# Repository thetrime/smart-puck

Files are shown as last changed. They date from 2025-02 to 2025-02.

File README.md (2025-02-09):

# Smart Puck
> But what if we went _smaller_?

# Configuration
You need three config files to run smart-puck. See the README.md file in the `config` directory

# Prerequisites
Obviously you need the hardware. 
FIXME: Details to be filled in once I work out what the hardware is ^^

You also need:
   * python
   * pip

# Installation
A shell script is available for bash users. (`mpremote cp *.py :` doesn't work on Windows). A workaround is to stop using Windows.

You can install it by just running `./install.sh` after plugging in your pico. Note that you also have to flash the Micropython firmware to it first.

That's it. Reboot and it's ready!

# To do list
## Code
   * Nothing? That doesn't sound right
## Hardware
   * Finish the schematic and PCB design
   * Create a STL for the case

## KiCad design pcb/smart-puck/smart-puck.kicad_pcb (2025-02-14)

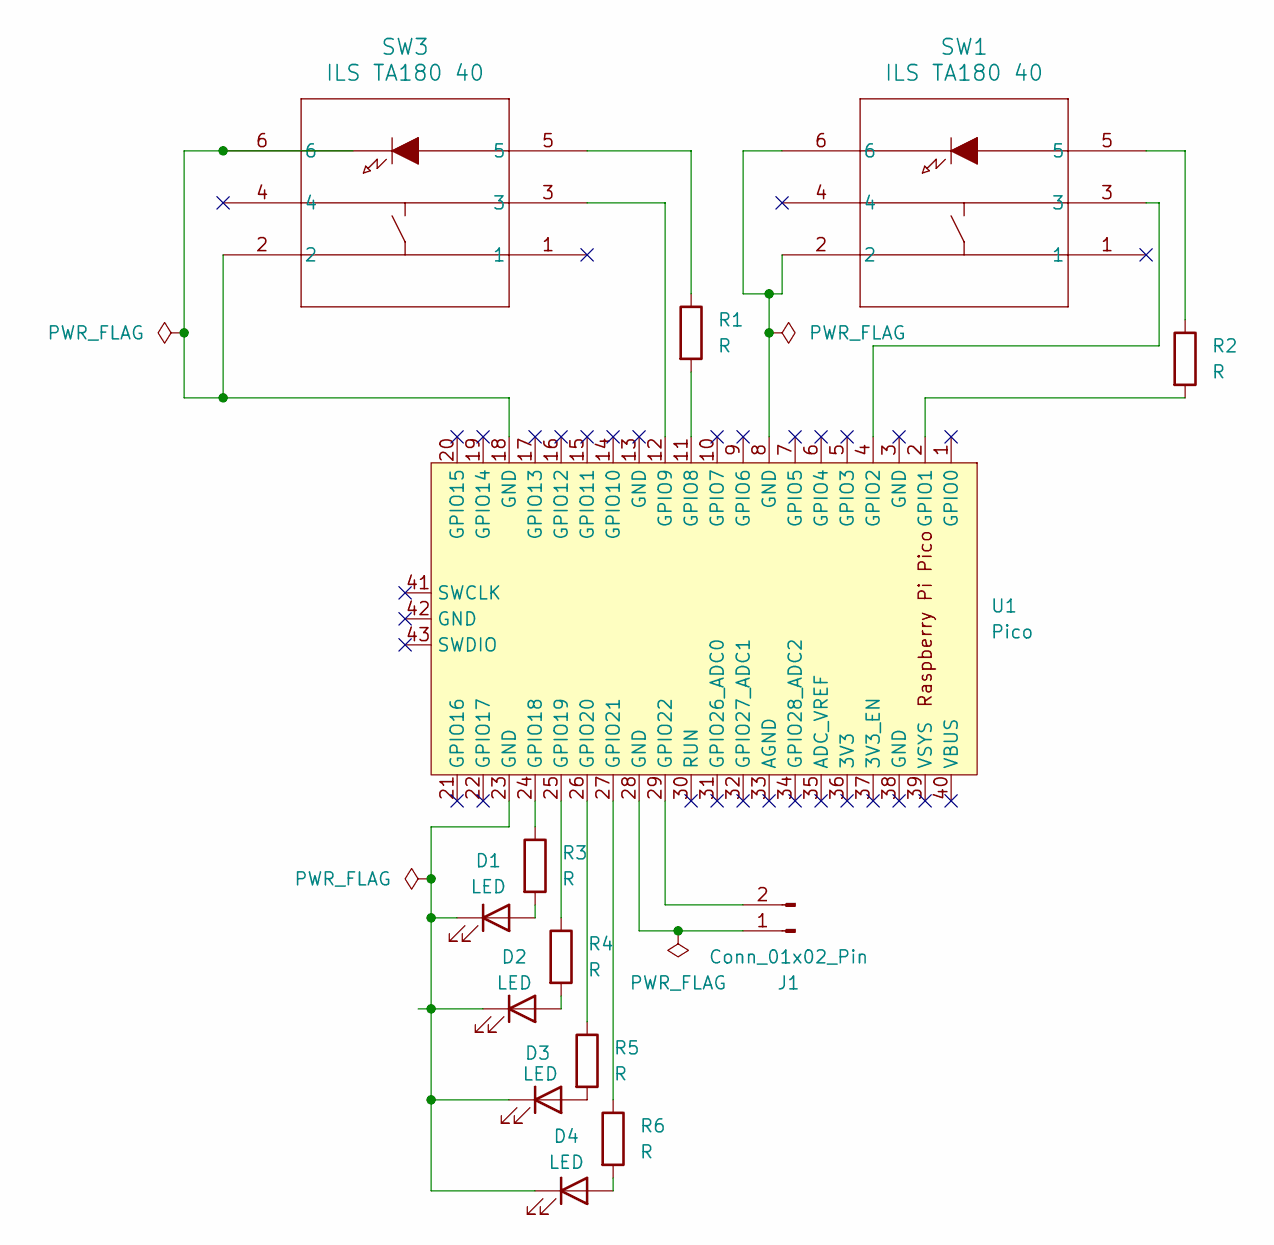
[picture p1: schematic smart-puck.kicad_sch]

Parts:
D1, D2, D3, D4: LED; LED_D5.0mm_Clear
J1: Conn_01x02_Pin; PinHeader_1x02_P2.54mm_Vertical
R1, R2, R3, R4, R5, R6: R; R_Axial_DIN0309_L9.0mm_D3.2mm_P12.70mm_Horizontal
SW1, SW3: ILS TA180 40; SW6_ILS TA180 40_CNK
U1: Pico; RPi_Pico_SMD_TH

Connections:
unnamed: D1.2 (A), R3.2
unnamed: D1.1 (K), D2.1 (K), D3.1 (K), D4.1 (K), U1.23 (GND)
unnamed: D2.2 (A), R4.2
unnamed: D3.2 (A), R5.2
unnamed: D4.2 (A), R6.2
unnamed: J1.1, U1.28 (GND)
unnamed: J1.2, U1.29 (GPIO22)
unnamed: R1.1, SW3.5
unnamed: R2.1, SW1.5
unnamed: SW1.2, SW1.6, U1.8 (GND)
unnamed: SW3.2, SW3.6, U1.18 (GND)
unnamed: R2.2, U1.2 (GPIO1)
unnamed: SW1.3, U1.4 (GPIO2)
unnamed: R1.2, U1.11 (GPIO8)
unnamed: SW3.3, U1.12 (GPIO9)
unnamed: R3.1, U1.24 (GPIO18)
unnamed: R4.1, U1.25 (GPIO19)
unnamed: R5.1, U1.26 (GPIO20)
unnamed: R6.1, U1.27 (GPIO21)

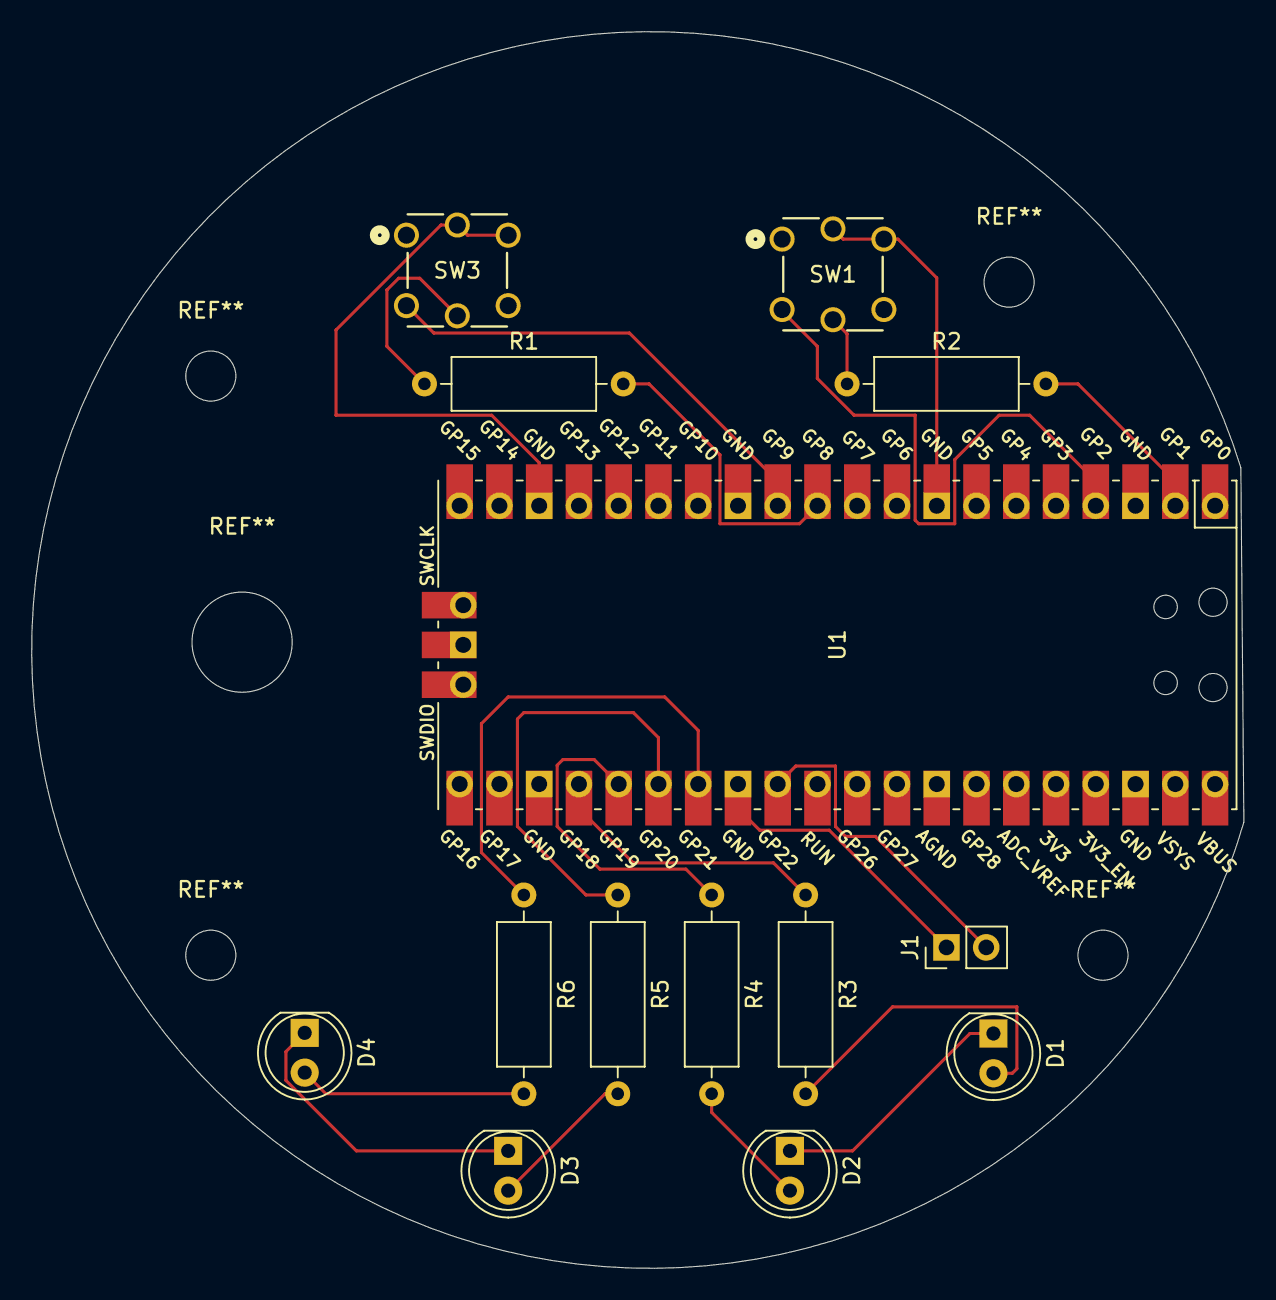
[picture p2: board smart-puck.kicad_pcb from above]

Board: 2 copper layers, 77.4 x 79.0 mm, 14 parts (0 on the bottom side), 19 nets.

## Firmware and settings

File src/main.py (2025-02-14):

"""
Entry point for the smart-puck application
"""

import asyncio
import network
import ntptime
from time import sleep
from scanner import scan_devices
from bins import bin_updater
from illuminated_switch import IlluminatedSwitch
from picozero import LED, Button, Buzzer
from airtag import airtag_setup, keyroller

NEARBY = -80

binLEDs = {
    "Blue": LED(18),
    "Green": LED(19),
    "Brown": LED(20),
    "Black": LED(21)
}

doorbell = Buzzer(22)

def ring_doorbell():
    print("Ding dong")
    doorbell.on(1, 1, False)

# The order of these has to match the order of the keys in the keys file
airtags = [
    IlluminatedSwitch(LED(1), Button(2), ring_doorbell),
    IlluminatedSwitch(LED(8), Button(9), ring_doorbell)
]

async def bins_updated(to):
    for colour, state in to:
        binLEDs[colour].value = state

def airtag_found(_name, index, rssi):
    if rssi > NEARBY:
        airtags[index].found()


async def main():
    binLEDs['Blue'].blink(1)
    with open('wifi', 'r') as file:
        ssid = file.readline().strip()
        password = file.readline().strip()

    wlan = network.WLAN(network.STA_IF)
    wlan.active(True)
    wlan.connect(ssid, password)
    while wlan.isconnected() == False:
        print('Waiting for wifi connection...')
        sleep(1)
    print("Connected!")
    binLEDs['Blue'].on()
    binLEDs['Green'].blink()

    # Now we have internet, set the time
    ntptime.settime()

    # To do: set up IO, check LED status source
    airtag_setup("keys")
    binLEDs['Green'].on()


    for led in binLEDs:
        binLEDs[led].off()

    # Start scanning
    asyncio.create_task(scan_devices(airtag_found))

    # Start updating bins
    asyncio.create_task(bin_updater(bins_updated))

    # Start keyroller
    asyncio.create_task(keyroller())

    # Wait forever
    await asyncio.Event().wait()

asyncio.run(main())

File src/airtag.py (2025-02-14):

"""
Find AirTags that you own without involving Apple in the process
"""
from binascii import unhexlify
from time import time
from collections import deque
import nist224p
from udatetime import format_date, iso8601_to_timestamp, timestamp_to_iso8601
import x963
import asyncio

keys = []
debugging = True
ENDIANNESS = "big"
WINDOW_SIZE = 8

def debug(string):
    if (debugging):
        print(string)

def handle_airtag(address, data, rssi, then):
    timestamp = time()
    first_byte = address[0] & 0b00111111
    key_prefix = address[1:].hex()
    if data[3] == 25:
       # Full key. Rest of the key is in val[8:..]
       # but we don't really need it - just the prefix
       special_bits = data[27]
    elif data[3] == 2:  # Partial key
       special_bits = data[5]
    else:
      print(f"Bad special bits {data[5]}")
    first_byte |= ((special_bits << 6) & 0b11000000)
    first_byte &= 0xff
    if first_byte < 0x10:
        key_prefix = "0x0" + hex(first_byte)[2] + key_prefix
    else:
        key_prefix = hex(first_byte) + key_prefix

    # Ok, look to see if this corresponds to one of our devices
    for index, key in enumerate(keys):
        for pindex, candidate in enumerate(list(key['advertised_prefixes'])):
            if candidate.startswith(key_prefix):
                print(f"Tag {key['name']} detected with prefix {key_prefix} (index {pindex}) at distance {rssi} at {format_date(timestamp)}Z")
                then(key['name'], index, rssi)
                return

    # print(f"Unknown Apple device with prefix {key_prefix} detected at strength {rssi} dBm at {format_date(timestamp)}Z")

def update_key(key, update_advertised):
    """
    Update a given key to the next key period
    """
    t_i = key['time'] + 15*60

    # Derive SK_1 from SK_0
    sk_1 = x963.kdf(key['shared_key'], 32, "update")
    
    print(f"Updating key {key['name']} to be current from {timestamp_to_iso8601(t_i)}Z")
    if update_advertised:
        
        # Derive AT_1 from SK_1
        at_1 = x963.kdf(sk_1, 72, "diversify")

        # Derive u_1 and v_1 from this
        u_1 = int.from_bytes(at_1[:36], ENDIANNESS)
        v_1 = int.from_bytes(at_1[36:], ENDIANNESS)

        # Reduce u and v into P-224 scalars
        u_1 = nist224p.reduce(u_1)
        v_1 = nist224p.reduce(v_1)

        # Compute P_1
        p_1 = nist224p.compute_result(u_1, key['p_0'], v_1)

        # The deque is initially empty
        if len(key['advertised_times']) == WINDOW_SIZE:
            debug(f"At {timestamp_to_iso8601(time())}Z we are dropping old key for {key['name']} that was valid at {timestamp_to_iso8601(key['advertised_times'][0])}Z: ${key['advertised_prefixes'][0]}")
        # We only really care about the first 6 bytes of the key.
        # In the near-to-owner case, this is all that is advertised..
        # The full key is only needed if we want to upload a finding-report to Apple
        new_prefix = hex(p_1[0])[0:14]
        print(f"Expecting prefix for {key['name']} to be {new_prefix} at {timestamp_to_iso8601(t_i)}Z (it is currently {timestamp_to_iso8601(time())}Z)")
        key['advertised_prefixes'].append(new_prefix)
        key['advertised_times'].append(t_i)
        print(f"We now have prefixes for {key['name']} from {timestamp_to_iso8601(key['advertised_times'][0])}Z to {timestamp_to_iso8601(key['advertised_times'][-1])}Z")

    # Regardless of the prefix stuff, we need to update these values
    key['time'] = t_i
    key['shared_key'] = sk_1


def parse_key_line(line):
    chunks = line.split(" ")
    sync_time = chunks[0]
    t_0 = iso8601_to_timestamp(sync_time)
    pkx = chunks[2][2:58]
    pky = chunks[2][58:]
    
    # Micropython doesnt have ecdsa support so I cannot just construct a Point.
    # Store p_0 as a tuple. We know which curve it is.
    p_0 = (int.from_bytes(unhexlify(pkx), ENDIANNESS), int.from_bytes(unhexlify(pky), ENDIANNESS))

    
    return {
        'time': t_0,
        'shared_key': unhexlify(chunks[1]),
        'p_0': p_0,
        'public_key': chunks[2],
        'name': " ".join(chunks[3:]),
        'advertised_prefixes': deque([], WINDOW_SIZE),
        'advertised_times': deque([], WINDOW_SIZE),
        'trace': unhexlify(chunks[1]),
        'trace_time': t_0
    }


def load_keys(filename):
    """
    Load stashed keys
    """
    keyfile = open(filename, "r", encoding="utf-8")
    min_t = time() - 12*60*60
    key_lines = keyfile.read().splitlines()
    for line in key_lines:
        if line.startswith("#"):
            continue
        key = parse_key_line(line)
        if key['time'] < min_t:
            min_t = key['time']
        keys.append(key)
    keyfile.close()


def rehydrate_keys():
    """
    Refresh all keys until they are at most 4 hours old
    """
    # Get all the keys up to date as of 4 hours ago
    oldest = time()
    for key in keys:
        i = 0
        original_time = key['time']
        if original_time < oldest:
            oldest = original_time
        print(f"Rehydrating key {key['name']} which was last stashed with timestamp {timestamp_to_iso8601(key['time'])}Z\n")
        while key['time'] < time() - 4 * 60 * 60:
            p = 100 * ((key['time'] - original_time) /
                       (time() - 4 * 60 * 60 - original_time))
            i += 1
            if i == 96:
                # Provide a periodic update in case this is going to take a long time
                i = 0
                print(f"{p:.2f}% {key['name']}")
                print(f"Key {key['name']} is at {timestamp_to_iso8601(key['time'])}Z")
            update_key(key, False)
        print(f"{100}% {key['name']}")
    return time() - oldest


def stash_keys(filename):
    """
    Save current key state
    """
    # Save keys so we dont have to do this next time
    print("Stashing keys")
    out = open(filename, "w", encoding="utf-8")
    for key in keys:
        out.write(
            timestamp_to_iso8601(key['trace_time']) +
            "Z " +
            key['trace'].hex() +
            " " +
            key['public_key'] +
            " " +
            key['name'] +
            "\n"
        )
    out.close()



def update_keys():
    for key in keys:
        while key['time'] < time() + (WINDOW_SIZE/2) * 15 * 60:
            print(f"Key {key['name']} needs updating because it has time {format_date(key['time'])}Z but the end window is {format_date(int(time() + (WINDOW_SIZE/2) * 15 * 60))}Z\n")
            update_key(key, True)
    print("Key schedule is current")
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

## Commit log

2025-02-02 Initial framework
2025-02-05 Restructure project significantly. Replace all the stuff micropython doesnt have with hand-written alternatives. Now I know how to do ECC arithmetic, I guess
    [airtag.py, main.py, nist224p.py]
2025-02-08 Fix a multitude of bugs
    [main.py]
2025-02-08 Do keyroll. Also the time needs to be set. The board has no way of knowing what the time is
2025-02-09 Get rid of the affine version. Add a status LED. Roll the keys before we start scanning
2025-02-09 Fix a typo. Also log where in the index we are to give an indicating of timing accuracy
    [airtag.py, main.py]
2025-02-09 Add the kicad project to git
    [smart-puck.kicad_pcb, smart-puck.kicad_sch]
2025-02-09 Use exising LEDs for status
2025-02-09 Fix a few shortcomings with the airtag code
    [airtag.py]
2025-02-11 Fix a multitude of bugs now I can test it on the device
    [airtag.py, main.py]
2025-02-13 Fix missing second arg in callback
    [illuminated_switch.py]
2025-02-13 Actually wire up the right pins. This all seems correct now
    [main.py]
2025-02-13 Add doorbell socket. oops
    [smart-puck.kicad_sch]
2025-02-14 More tweaks to various bits. That async callback was a big mistake
    [illuminated_switch.py, main.py, scanner.py]
2025-02-14 update PCB. Align components. Add some mounting holes. Add a big hole in case we need to mount the doorbell stuff underneath
    [smart-puck.kicad_pcb, smart-puck.kicad_sch]
